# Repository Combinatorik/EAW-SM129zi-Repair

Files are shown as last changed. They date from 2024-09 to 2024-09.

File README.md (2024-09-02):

# EAW-SM129zi-Repair
Replacement parts for Easter Acoustical Works SM129zi legacy monitors.  Parts include a replacement 4-layer PCB for the speak-on connectors and a better, aluminum, mount to prevent the PCB from flexing.

If you have these monitors and want to repair them feel free to use the parts found in the repository and the instructions in this Readme.

## Ordering Replacements
Replacements consist of electrical components and mechanical components.  This section outlines how to order replacements for both.

### Ordering Replacement PCBs
For this section, we will be using OSHPARK to order replacements simply because they're cheap.  Tons of other fabricators exist out there however.  With the fabrication files you are free to send them to whatever fabricator strikes your fancy and they'll be able to print the circuits for you.

    1.  Download Electrical/Fabrication Files.zip
    2.  Navigate to oshpark.com and drag and drop the zip file onto the "Let's Get Started" banner.
    3.  Order as many parts as needed.

### Orderdering Replacement Mounting Bracket
For this section, we will be using Xometry to order replacements simply because it's easy.  Tons of other fabricators exist.  If you want to fabricate your own a PDF of the part spects is uploaded as well.

	1.  Download Mechanical/Mounting Plate v2.step
	2.  Navigate to xometry.com and drag and drop the step file onto the "Start Your Instant Quote" box.
	3.  Click on "Configure Part" and select "Black Anodized" as the finish.
	4.  Order as many parts as needed.

## Assembly
Assembly is fairly straight forward.  The following tools are required to assemble a complete replacement:

	1.  Soldering iron
	2.  Small Phillips screw driver

In addition, the following tools are optional to modify the Speak-On connectors:

	1.  Drill press/hand drill
	2.  #30 drill bit

Follow these steps to assemble the PCB and mounting bracket:

	1.  Solder the spade connectors to the PCB.  Ensure they are inserted onto the backside of the PCB, the side that has no white text.
	2.  Solder the Speak-On connectors to the PCB.  Ensure they are inserted onto the front of the PCB, the side that has text.
	3.  Mount Speak-On connectors onto mounting plate and screw screws into lock nuts on backside.

The following steps are optional for additional.  They make the connections stronger, further preventing damage to connectors when Speak-On cables plugged/unplugged.

	1.  For the holes on the mounting plate that have no Speak-On connector holes on them, drill holes using the drill bit.
	2.  Insert additional screws and tighten them using lock nuts.

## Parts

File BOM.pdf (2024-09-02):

# Bill of Materials (BOM)

Item # | Description | Vendor | Part Number | Qty | Cost | Link to Where to Purchase 1 | Speak-On Connector | Amazon | NL4MDXX-V | 2 | $6.80 | Link 2 | Spade Connector | Digikey | 63824-1 | 8 | $0.88 | Link 3 | Screw | McMaster-Carr | 91249A620 | 4 | $0.61 | Link 4 | Lock Nut | McMaster-Carr | 90631A006 | 4 | $0.17 | Link
Total | $8.46

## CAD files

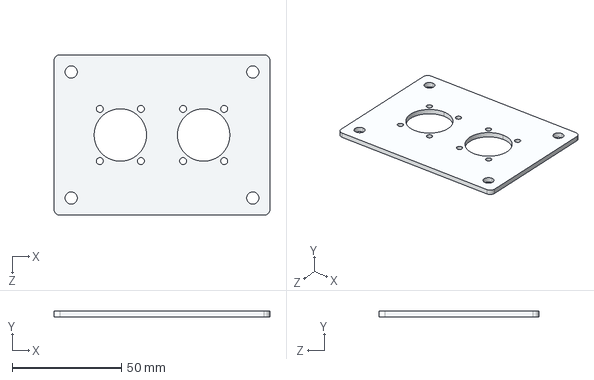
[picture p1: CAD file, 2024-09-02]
Mechanical/Mounting Plate v2.STEP
98.8 x 2.54 x 73.4 mm

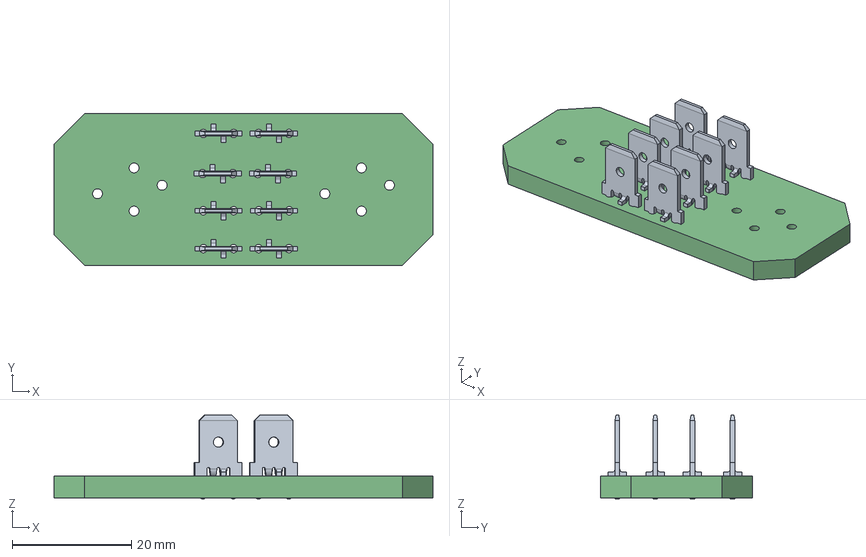
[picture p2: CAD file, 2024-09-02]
Mechanical/Solidworks/aux files/PCB V2.3 STEP.step
63.5 x 25.4 x 14.0 mm
c-63824-1-ad-3d x 8

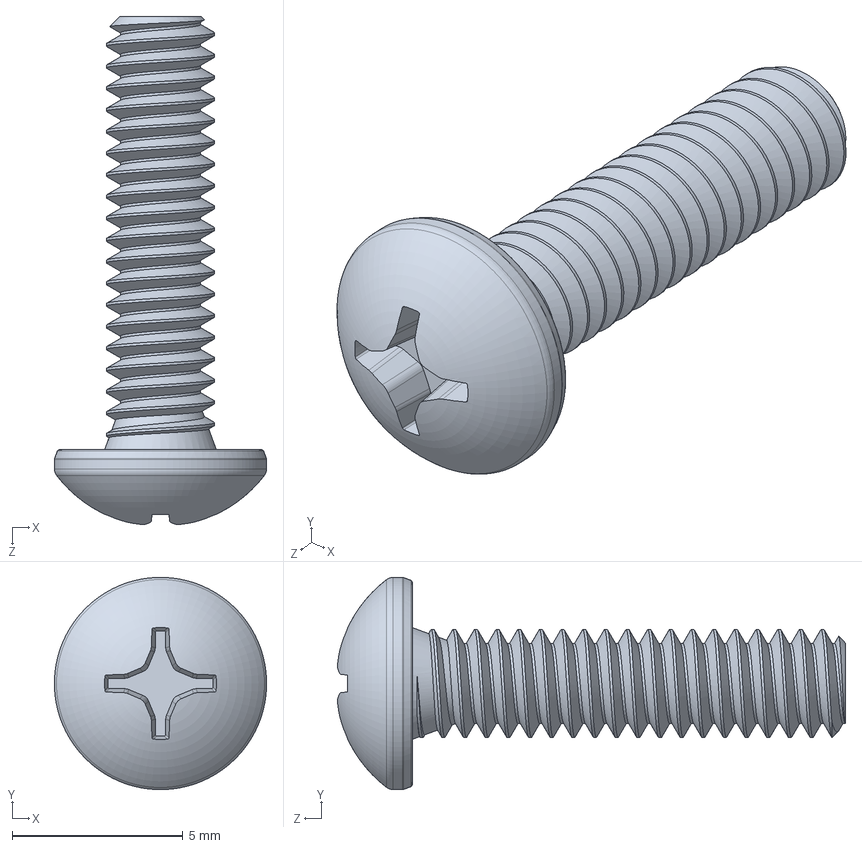
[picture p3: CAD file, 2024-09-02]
Mechanical/Solidworks/aux files/91249A620_Black-Oxide 18-8 Stainless Steel Pan Head Phillips Screws.SLDPRT
6.22 x 6.22 x 14.9 mm

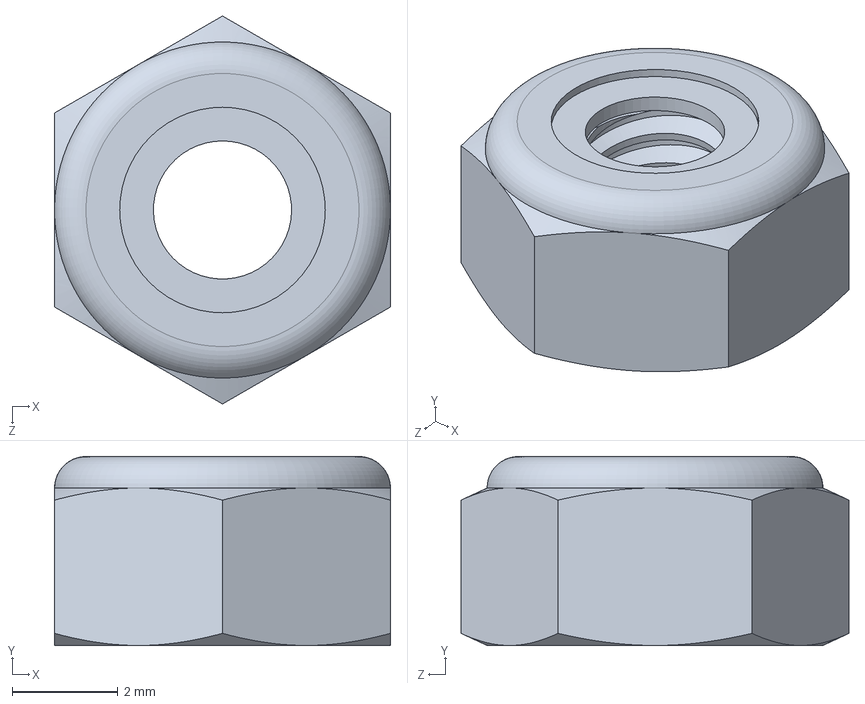
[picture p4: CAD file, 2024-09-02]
Mechanical/Solidworks/aux files/90631A006_Low-Strength Steel Nylon-Insert Locknut.SLDPRT
6.35 x 3.57 x 7.33 mm

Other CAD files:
Mechanical/Solidworks/Mounting Plate 2.SLDPRT
Mechanical/Solidworks/Assembly V2.3 Drawing.SLDDRW
Mechanical/Solidworks/Mounting Plate v2 Drawing.SLDDRW

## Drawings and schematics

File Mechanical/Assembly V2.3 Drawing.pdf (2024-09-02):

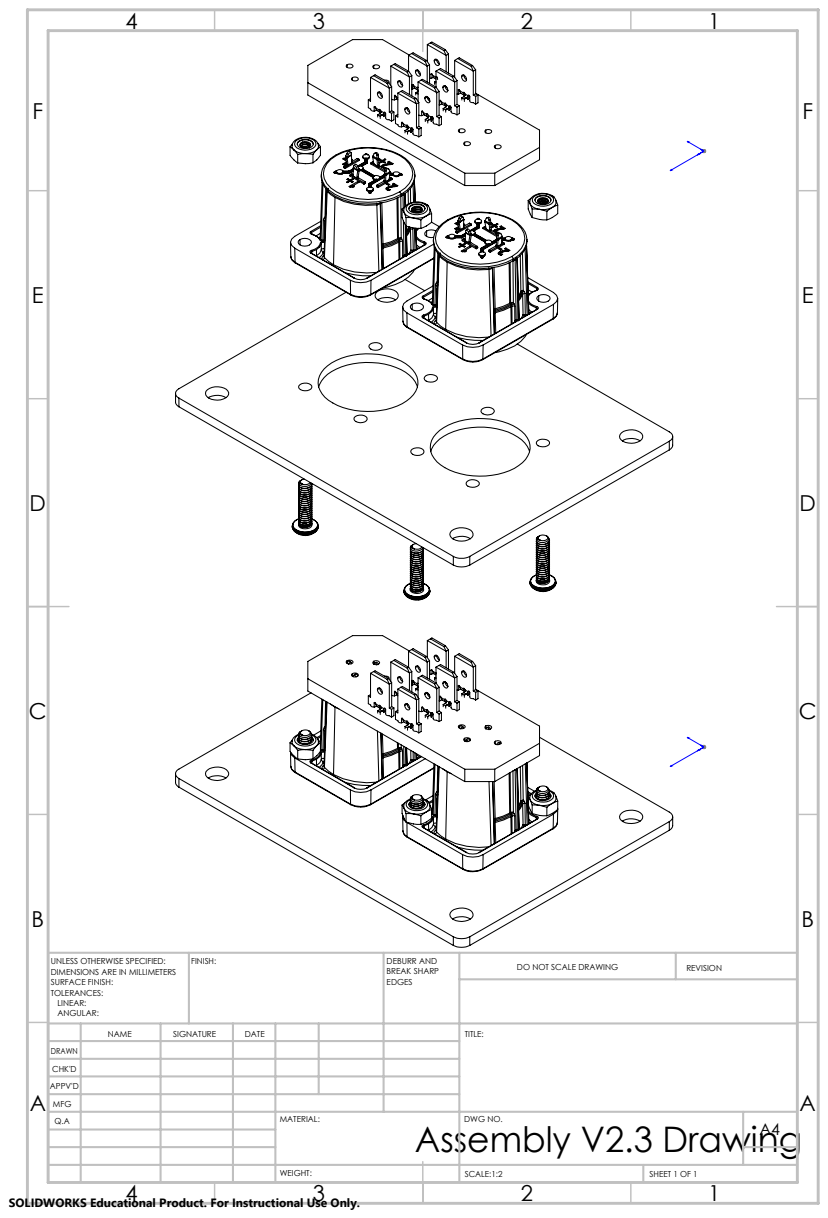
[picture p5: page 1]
FINISH:; DEBURR AND; BREAK SHARP; DO NOT SCALE DRAWING; REVISION; SCALE:1:2; SHEET 1 OF 1

UNLESS OTHERWISE SPECIFIED:
DIMENSIONS ARE IN MILLIMETERS
SURFACE FINISH:
TOLERANCES:
LINEAR:
ANGULAR:

NAME | SIGNATURE | DATE | | | | TITLE:

DRAWN
CHK'D
APPV'D
MFG
Q.A | | | | MATERIAL: Assembly V2.3 Drawing | DWG NO. | A4

SOLIDWORKS Educational Product. For Instructional Use Only.

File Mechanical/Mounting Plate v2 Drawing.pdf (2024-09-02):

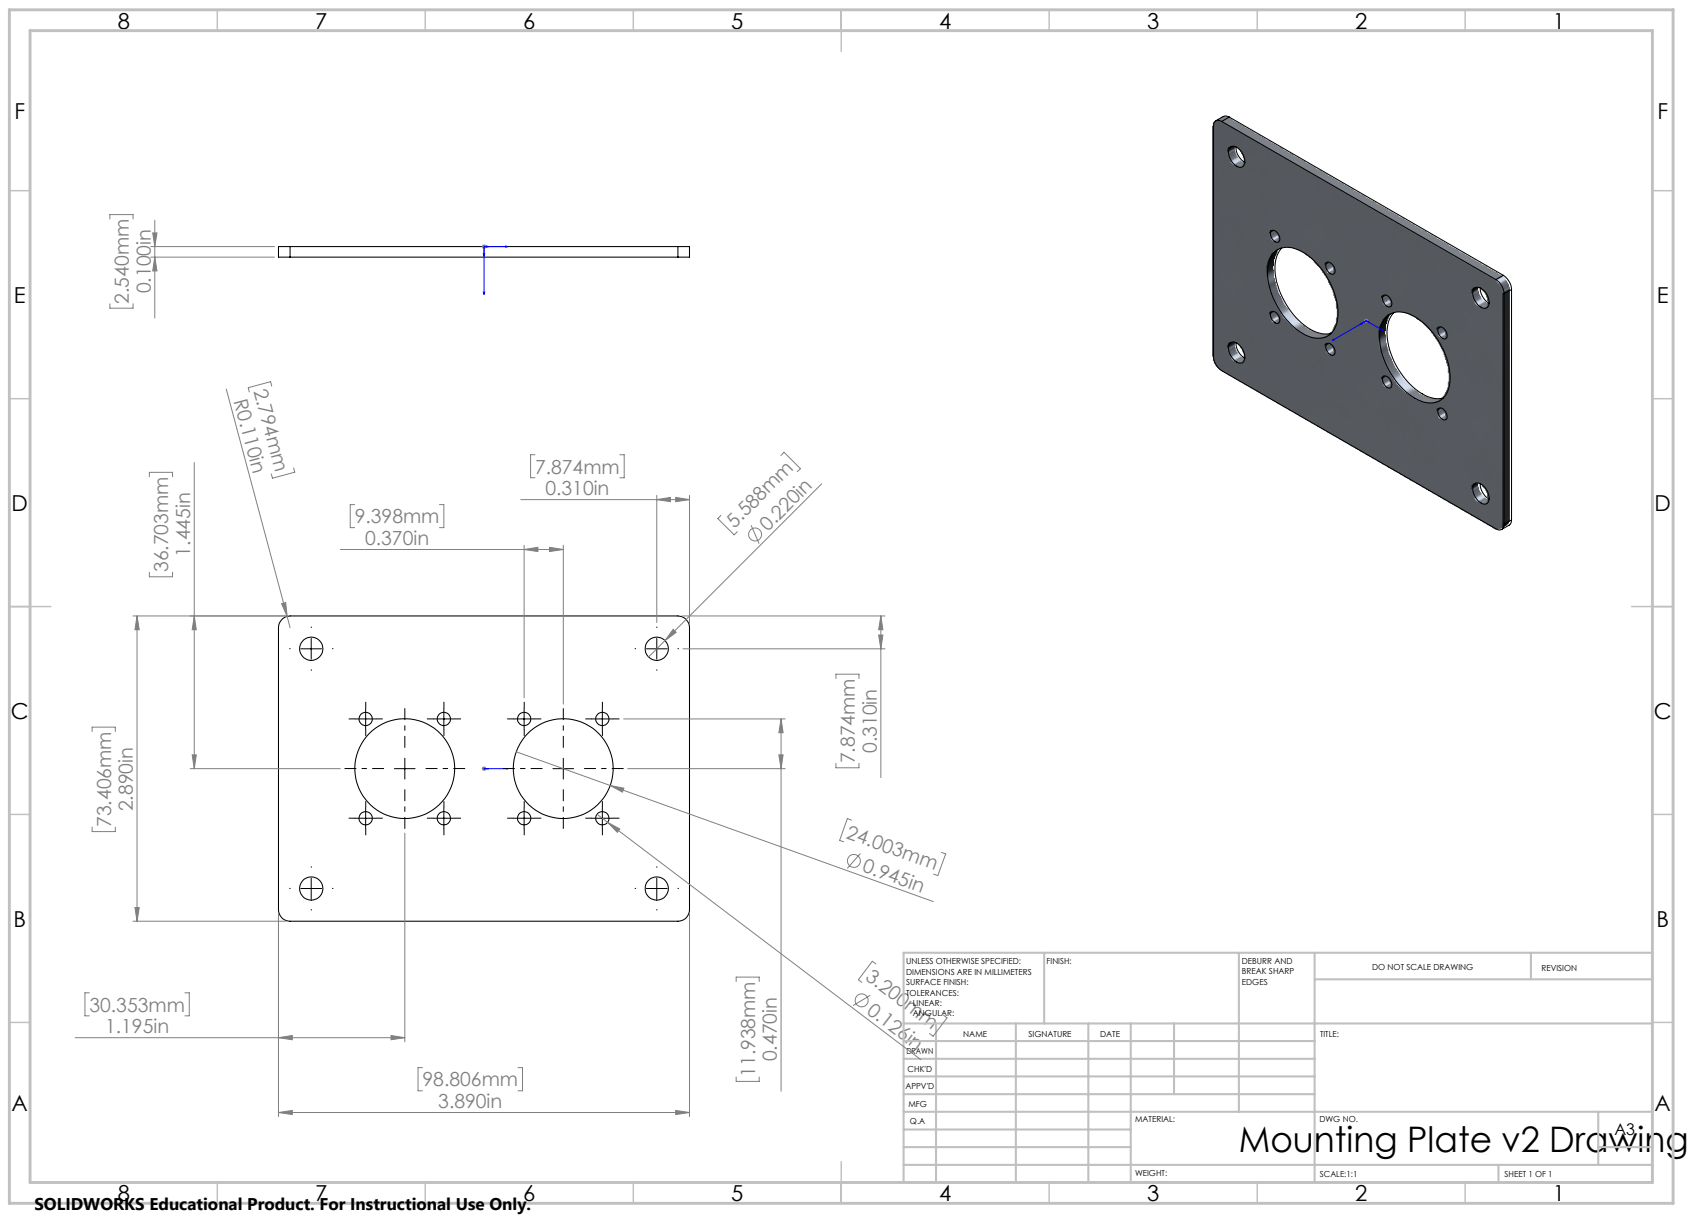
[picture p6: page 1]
FINISH:; DEBURR AND; BREAK SHARP; DO NOT SCALE DRAWING; REVISION; SCALE:1:1; SHEET 1 OF 1

UNLESS OTHERWISE SPECIFIED:
DIMENSIONS ARE IN MILLIMETERS
SURFACE FINISH:
TOLERANCES:
LINEAR:
ANGULAR:

NAME | SIGNATURE | DATE | | | | TITLE:

DRAWN
CHK'D
APPV'D
MFG
Q.A | | | | MATERIAL: | DWG NO. | A3

Mounting Plate v2 Drawing

SOLIDWORKS Educational Product. For Instructional Use Only.

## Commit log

2024-09-02 Initial commit
    Upload fabrication files, Solidworks files, and readme.
    [Mounting Plate 2.SLDPRT, Mounting Plate v2 Drawing.SLDDRW, Mounting Plate v2.STEP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]
2024-09-02 Minor updates
    Added assembly instructions. Added BOM file to main directory. Added Altium circuit. Added screws and nuts to Solidworks assembly. Added drawing for assembly. Cleaned up mounting plate drawing a bit.
    [90631A006_Low-Strength Steel Nylon-Insert Locknut.SLDPRT, 91249A620_Black-Oxide 18-8 Stainless Steel Pan Head Phillips Screws.SLDPRT, Assembly V2.3 Drawing.SLD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]
